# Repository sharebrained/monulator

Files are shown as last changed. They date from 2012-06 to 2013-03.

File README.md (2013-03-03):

monulator
=========

Data visualization gadget featuring an analog panel meter and RGB LED controlled over USB

Sub-Projects
============

* monulator-arm-lpc11u: NXP LPC11U14-based Monulator, the second (but probably not *last*) implementation.
* monulator-usb-avr8: Atmel AVR8-based Monulator, the first implementation.

License
=======

Please see the license files within individual project directories.

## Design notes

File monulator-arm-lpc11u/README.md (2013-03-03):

monulator-usb-avr8
==================

Data visualization gadget featuring an analog panel meter and RGB LED
controlled via USB or Wi-Fi. More information in
[this blog post](http://www.sharebrained.com/2012/05/30/the-monulator/).

Status
======

This version of the Monulator project is tested with an NXP LPC11U14
development board, TI CC3000 evaluation module, and a lot of jumper wires.
A custom circuit board design and prototype is pending.
    
License
=======

The associated software is provided under a GPLv2 license:

Copyright (C) 2013 Jared Boone, ShareBrained Technology, Inc.

This program is free software; you can redistribute it and/or
modify it under the terms of the GNU General Public License
as published by the Free Software Foundation; either version 2
of the License, or (at your option) any later version.

This program is distributed in the hope that it will be useful,
but WITHOUT ANY WARRANTY; without even the implied warranty of
MERCHANTABILITY or FITNESS FOR A PARTICULAR PURPOSE.  See the
GNU General Public License for more details.

You should have received a copy of the GNU General Public License
along with this program; if not, write to the Free Software
Foundation, Inc., 51 Franklin Street, Fifth Floor, Boston, MA
02110-1301, USA.

Contact
=======

ShareBrained Technology, Inc.

<http://www.sharebrained.com/>

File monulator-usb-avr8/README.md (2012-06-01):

monulator-usb-avr8
==================

Data visualization gadget featuring an analog panel meter and RGB LED
controlled over USB. More information in [this blog post](http://www.sharebrained.com/2012/05/30/the-monulator/).

Status
======

This board has been fabricated and assembled, and works well. The
project is still under heavy development, so expect radical changes
in the design.

Bill of Materials
=================

See the included monulator-usb-avr8-bom.csv. I believe it's up-to-date with the
components and values I used in my last build of this board. But do re-check
against the respective datasheets.

Requirements
============

* [EAGLE 5.11 Freeware, Light, Hobbyist, Standard, or Professional]
  (http://www.cadsoftusa.com/shop/pricing/)

Files
=====

* monulator-usb-avr8.sch:

    Schematic for circuit board, drawn in EAGLE 5.11.

* monulator-usb-avr8-schematic.pdf:

    Schematic for circuit board, in Adobe PDF format.

* monulator-usb-avr8-bom.csv:

    List of components used in the circuit board, including recommended vendors
    and prices.

* monulator-usb-avr8.brd:

    Circuit board layout, drawn in EAGLE 5.11.

* monulator-usb-avr8.dru:

    EAGLE design rules used to validate schematic and PCB.

* monulator-usb-avr8-laen2.cam:

    EAGLE CAM file used to generate Gerber RS-274X files for
    circuit board production via
    [Laen's two-layer PCB Order]
    (http://dorkbotpdx.org/wiki/pcb_order).
    
License
=======

This hardware design is licensed under a
[Creative Commons Attribution-ShareAlike 3.0 Unported License]
(http://creativecommons.org/licenses/by-sa/3.0/).

The associated software is provided under a BSD two-clause license:

Copyright (c) 2011, ShareBrained Technology, Inc.
All rights reserved.

Redistribution and use in source and binary forms, with or without
modification, are permitted provided that the following conditions are met:

o Redistributions of source code must retain the above copyright notice, this
  list of conditions and the following disclaimer.

o Redistributions in binary form must reproduce the above copyright notice,
  this list of conditions and the following disclaimer in the documentation
  and/or other materials provided with the distribution.

THIS SOFTWARE IS PROVIDED BY THE COPYRIGHT HOLDERS AND CONTRIBUTORS "AS IS"
AND ANY EXPRESS OR IMPLIED WARRANTIES, INCLUDING, BUT NOT LIMITED TO, THE
IMPLIED WARRANTIES OF MERCHANTABILITY AND FITNESS FOR A PARTICULAR PURPOSE
ARE DISCLAIMED. IN NO EVENT SHALL THE COPYRIGHT HOLDER OR CONTRIBUTORS BE
LIABLE FOR ANY DIRECT, INDIRECT, INCIDENTAL, SPECIAL, EXEMPLARY, OR
CONSEQUENTIAL DAMAGES (INCLUDING, BUT NOT LIMITED TO, PROCUREMENT OF
SUBSTITUTE GOODS OR SERVICES; LOSS OF USE, DATA, OR PROFITS; OR BUSINESS
INTERRUPTION) HOWEVER CAUSED AND ON ANY THEORY OF LIABILITY, WHETHER IN
CONTRACT, STRICT LIABILITY, OR TORT (INCLUDING NEGLIGENCE OR OTHERWISE)
ARISING IN ANY WAY OUT OF THE USE OF THIS SOFTWARE, EVEN IF ADVISED OF THE
POSSIBILITY OF SUCH DAMAGE.

Contact
=======

ShareBrained Technology, Inc.

<http://www.sharebrained.com/>

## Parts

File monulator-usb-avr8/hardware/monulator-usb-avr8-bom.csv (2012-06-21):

Ref Des | Mfr | Mfr Part | Description | Vendor | Vendor Part | Qty
C1,2 | TDK | C1608C0G1H180J | CAP CER 18PF 50V 5% NP0 0603 | Digi-Key | 445-1272-1-ND | 2
C3,4,9 | Murata | GRM188F51C105ZA01D | CAP CER 1UF 16V Y5V 0603 | Digi-Key | 490-1582-1-ND | 3
C5,6 | Murata | GRM188F51C104ZA01D | CAP CER .1UF 16V Y5V 0603 | Digi-Key | 490-1577-1-ND | 2
C7,8 |  |  | do not populate |  |  | 0
C10 |  |  | do not populate |  |  | 0
C11 | Murata | GRM188R60J475ME19D | CAP CER 4.7UF 6.3V 20% X5R 0603 | Digi-Key | 490-5421-1-ND | 1
D1 | Cree | CLP6C-FKB-CM1Q1H1BB7R3R3 | LED RED/GREEN/BLUE PLCC6 SMD | Digi-Key | CLP6C-FKB-CM1Q1H1BB7R3R3CT-ND | 1
F1 | Bourns | MF-NSMF050-2 | PTC RESETTABLE .50A 13.2V 1206 | Digi-Key | MF-NSMF050-2TR-ND | 1
FB1 | TDK | MPZ1608S601A | FERRITE CHIP BEAD 600 OHM SMD | Digi-Key | 445-2205-1-ND | 1
J1 | On Shore Technology | USB-B1KSB6 | CONN USB TYPE B VERTICAL BLACK | Digi-Key | ED2981-ND | 1
J2 |  | 85C1-A | 5mA panel meter |  |  | 1
J3A,J3B | Sullins | NPPN101BFCN-RC | CONN RECEPT 2MM SINGLE STR 10POS | Digi-Key | S5751-10-ND | 2
J4,5 |  |  | 2-pin 0.1” header |  |  | 2
J6 |  |  | 2x3-pin 0.1” header |  |  | 1
Q2,3,4 | NXP | 2N7002F,215 | MOSFET N-CH 60V 475MA SOT23 | Digi-Key | 568-5983-1-ND | 3
R1,2 | Yageo | RC0603JR-0722RL | RES 22 OHM 1/10W 5% 0603 SMD | Digi-Key | 311-22GRCT-ND | 2
R3 | Yageo | RC0603FR-07137RL | RES 137 OHM 1/10W 1% 0603 SMD | Digi-Key | 311-137HRCT-ND | 1
R4,5 | Yageo | RC0603FR-0776R8L | RES 76.8 OHM 1/10W 1% 0603 SMD | Digi-Key | 311-76.8HRCT-ND | 2
R6 | Yageo | RC0603FR-07590RL | RES 590 OHM 1/10W 1% 0603 SMD | Digi-Key | 311-590HRCT-ND | 1
R7 | Yageo | RC0603FR-07100RL | RES 100 OHM 1/10W 1% 0603 SMD | Digi-Key | 311-100HRCT-ND | 1
R8,9 | Yageo | RC0603FR-0710KL | RES 10.0K OHM 1/10W 1% 0603 SMD | Digi-Key | 311-10.0KHRCT-ND | 2
SW1 | TE Connectivity | FSM4JSMA | SWITCH TACTILE SPST-NO 0.05A 12V | Digi-Key | 450-1129-ND | 1
U1 | Atmel | AT90USB162-16AU | MCU AVR USB 16K FLASH 32-TQFP | Digi-Key | AT90USB162-16AU-ND | 1
U2 | Torex | XC6222B331MR-G | IC REG LDO 3.3V SOT-25 | Digi-Key | 893-1143-1-ND | 1
X1 | TXC | 7V-16.000MAAE-T | CRYSTAL 16.000 MHZ 12PF SMD | Digi-Key | 887-1462-1-ND | 1

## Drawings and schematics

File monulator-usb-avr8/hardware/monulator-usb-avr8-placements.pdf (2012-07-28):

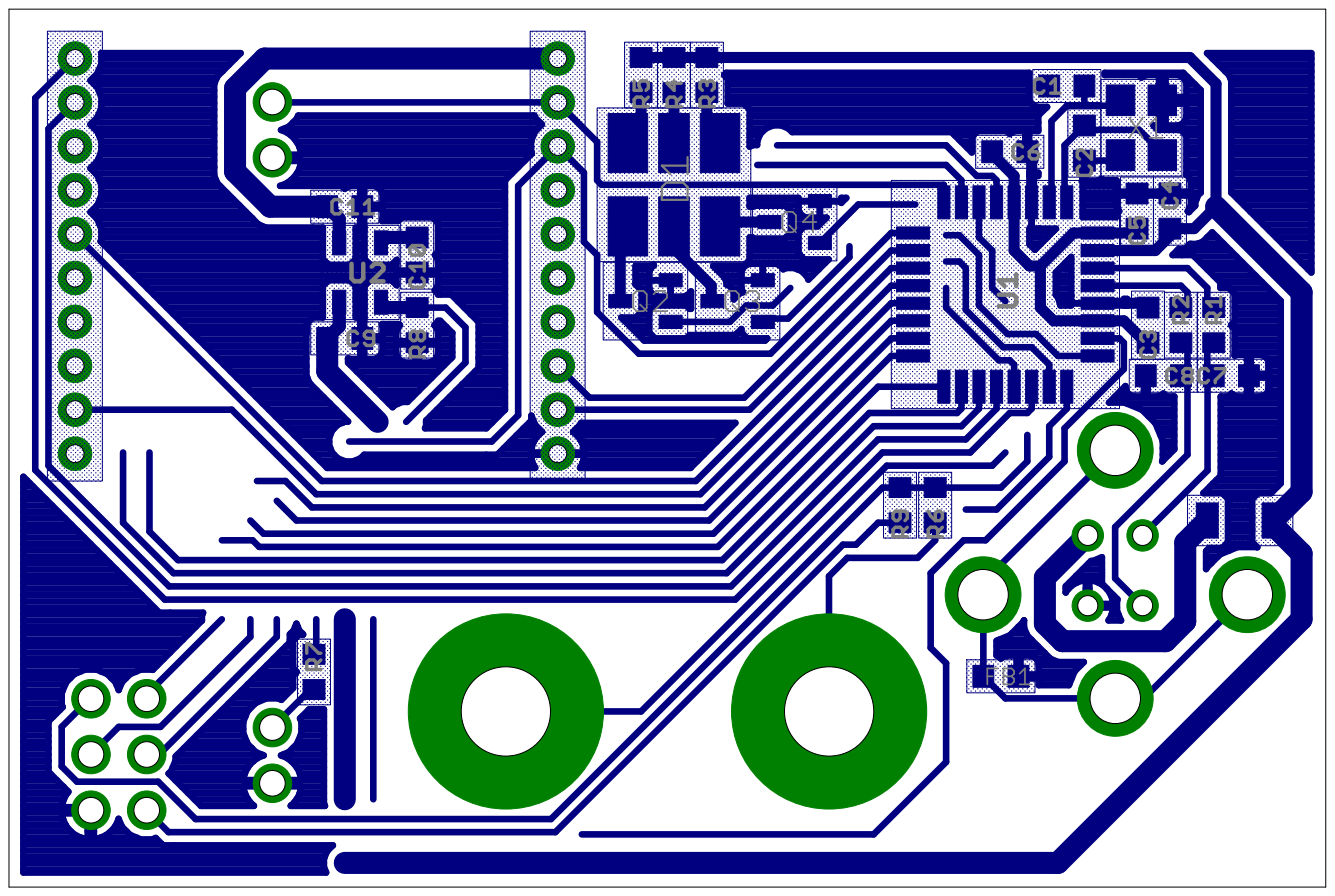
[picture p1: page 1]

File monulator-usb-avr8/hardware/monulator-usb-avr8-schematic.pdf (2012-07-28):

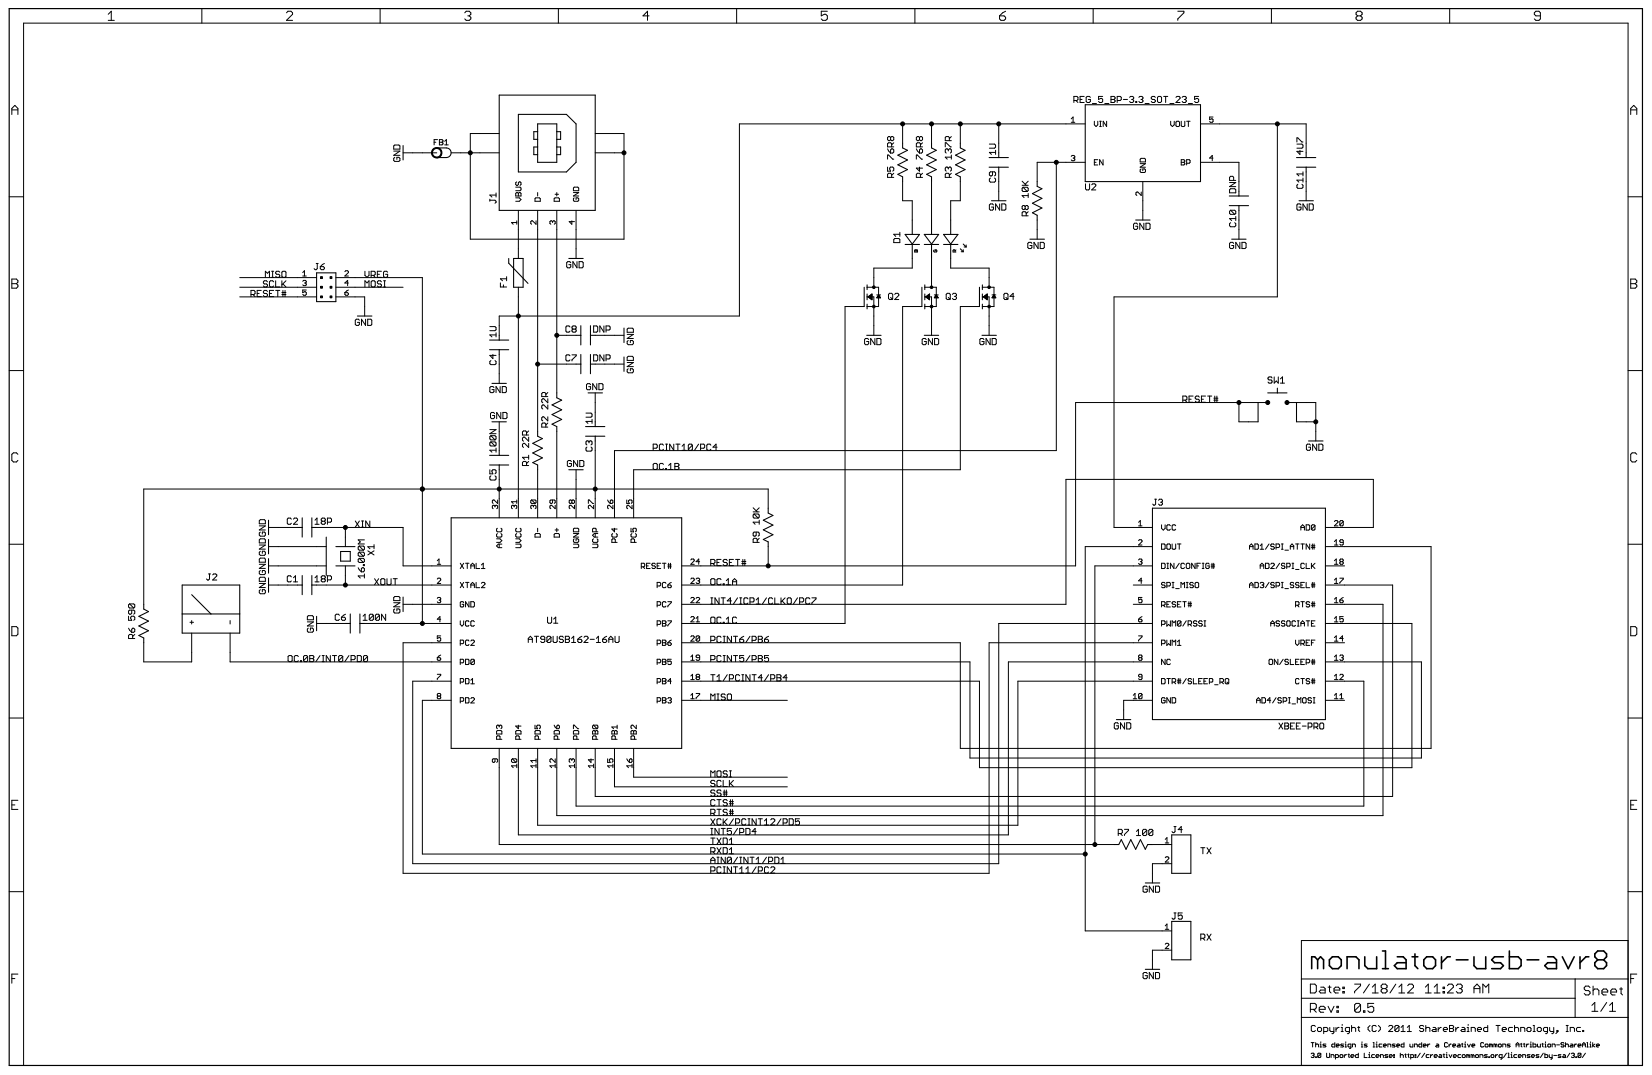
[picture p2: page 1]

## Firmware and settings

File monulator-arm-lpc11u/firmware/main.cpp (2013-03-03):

/* 
 * Monulator ARM LPC11U14 application.
 * 
 * Copyright (C) 2013 Jared Boone, ShareBrained Technology, Inc.
 * 
 * This file is part of the Monulator project.
 * 
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
 * You should have received a copy of the GNU General Public License
 * along with this program; if not, write to the Free Software
 * Foundation, Inc., 51 Franklin Street, Fifth Floor, Boston, MA
 * 02110-1301, USA.
 */

#include "lpc11u.h"
#include "serial.h"

#include "cc3000.h"
#include "cc3000_spi.h"
#include "cc3000_nvram.h"
#include "cc3000_wlan.h"
#include "cc3000_socket.h"

#include "http.h"
#include "csv_parser.h"
#include "aurora_swpc.h"

//#include "patch.h"

#include "TEST_WLAN_INFO.h"

#include <cstdint>

void turn_on_crystal_oscillator() {
	SCB.SYSOSCCTRL = 0;
	SCB.enable_power(SCB.PDRUNCFG_SYSOSC);
}

void start_system_pll() {
	// Start up system PLL: 12MHz crystal to 48 MHz.
	SCB.set_system_pll_dividers(1, 3);
	SCB.set_system_pll_clock_source(SCB.SYSPLLCLKSEL_SEL_CRYSTAL_OSCILLATOR);
	SCB.enable_power(SCB.PDRUNCFG_SYSPLL);
	SCB.wait_for_system_pll_lock();
}

void set_main_clock_to_system_pll() {
	// Switch main (and system clocks) to system PLL
	SCB.set_main_clock_source(SCB.MAINCLKSEL_SEL_PLL_OUTPUT);
}

void start_usb_pll() {
	// Start up USB PLL: 12MHz crystal to 48 MHz.
	SCB.set_usb_pll_dividers(1, 3);
	SCB.set_usb_pll_clock_source(SCB.USBPLLCLKSEL_SEL_SYSTEM_OSCILLATOR);
	SCB.enable_power(SCB.PDRUNCFG_USBPLL);
	SCB.wait_for_usb_pll_lock();
}

void set_usb_clock_to_main_clock() {
	// NOTE: Both clock sources must be running in order to switch!
	// So if you want to use the main clock instead of the USB PLL,
	// you have to start the USB PLL in order to switch away from it!
	SCB.set_usb_clock_source(SCB.USBCLKSEL_SEL_MAIN_CLOCK);
}

void set_usb_clock_to_usb_pll() {
	SCB.set_usb_clock_source(SCB.USBCLKSEL_SEL_USB_PLL_OUT);
}

void enable_peripheral_clocks() {
	SCB.set_system_clock_divider(1);
	SCB.enable_clocks(
		  SCB.SYSAHBCLKCTRL_GPIO
		//| SCB.SYSAHBCLKCTRL_CT16B0
		//| SCB.SYSAHBCLKCTRL_CT16B1
		//| SCB.SYSAHBCLKCTRL_CT32B0
		| SCB.SYSAHBCLKCTRL_CT32B1
		| SCB.SYSAHBCLKCTRL_USART
		| SCB.SYSAHBCLKCTRL_SSP1
		| SCB.SYSAHBCLKCTRL_USB
		| SCB.SYSAHBCLKCTRL_IOCON
		//| SCB.SYSAHBCLKCTRL_RAM1	// Available on larger parts.
		| SCB.SYSAHBCLKCTRL_USBRAM
	);
}

void enable_clock_output() {
	SCB.set_clkout_clock_source(SCB.CLKOUTSEL_SEL_MAIN_CLOCK);
	SCB.set_clkout_divider(48);
	IOCON.PIO0_1 = 1;
}

void configure_pins() {
	// Enable LED output
	GPIO_PORT.DIR0 |=
		(1 << 7)
		;
	
	// CT16B0_MAT PWM outputs
	/*
	IOCON.PIO0_8 = 2;
	IOCON.PIO0_9 = 2;
	IOCON.PIO1_15 = 2;
	*/
	
	// CT32B1_MAT PWM outputs
	/*
	IOCON.TDO_PIO0_13 = 3;	// CT32B1_MAT0
	IOCON.TRST_PIO0_14 = 3;	// CT32B1_MAT1
	IOCON.PIO0_16 = 2;		// CT32B1_MAT3
	*/
	
	// Configure USART
	IOCON.PIO0_18 = 1;		// RXD
	IOCON.PIO0_19 = 1;		// TXD
	
	// Configure USB I/O
	IOCON.PIO0_3 = 1;		// USB_VBUS
	IOCON.PIO0_6 = 1;		// USB_CONNECT#
	SCB.enable_power(SCB.PDRUNCFG_USBPAD);
	
	// Configure CC3000 EN and IRQ
	cc3000.disable();
	
	// CC3000_EN:   PIO, output
	GPIO_PORT.DIR1 |= (1 << 22);
	IOCON.PIO1_22 = 0;		
	
	// CC3000_IRQ#: PIO, input
	// Pull-up ensures IRQ# is inactive when module is off.
	GPIO_PORT.DIR1 &= ~(1 << 27);
	IOCON.PIO1_27 = (2 << 3); // pull-up resistor enabled.
	
	// CC3000_CS#:  PIO, output
	GPIO_PORT.DIR1 |= (1 << 23);
	IOCON.PIO1_23 = 0;
	
	// Configure SPI I/O
	IOCON.PIO1_20 = 2;		// CC3000_SCLK: SCLK1
	IOCON.PIO0_21 = 2;		// CC3000_MOSI: MOSI1
	IOCON.PIO1_21 = 2;		// CC3000_MISO: MISO1
}

void configure_led_pwm_timer_ct16b0() {
	// Configure 16 bit timer/match 0
	CT16B0.TCR = (1 << 1);
	CT16B0.TCR = 0;

	CT16B0.PC = 0;
	CT16B0.TC = 0;

	CT16B0.PR = 0;
	
	CT16B0.MR[0] = 12000;	// Channel 1 low time
	CT16B0.MR[1] = 24000;	// Channel 2 low time
	CT16B0.MR[2] = 36000;	// Channel 3 low time
	CT16B0.MR[3] = 48000;	// Cycle count.
	CT16B0.MCR = (1 << 10);
	CT16B0.EMR = 0;
	CT16B0.PWMC =
		  (1 << 2)
		| (1 << 1)
		| (1 << 0)
		;
		
	CT16B0.TCR = (1 << 0);
}

void configure_led_pwm_timer_ct32b1() {
	// Configure 32 bit timer/match 1
	CT32B1.TCR = (1 << 1);
	CT32B1.TCR = 0;

	CT32B1.PC = 0;
	CT32B1.TC = 0;

	CT32B1.PR = 0;
	
	CT32B1.MR[0] = 12000;	// Channel 1 low time
	CT32B1.MR[1] = 24000;	// Channel 2 low time
	CT32B1.MR[2] = 48000;	// Cycle count.
	CT32B1.MR[3] = 36000;	// Channel 4 low time
	CT32B1.MCR = (1 << 7);
	CT32B1.EMR = 0;
	CT32B1.PWMC =
		  (1 << 3)
		| (1 << 1)
		| (1 << 0)
		;
		
	CT32B1.TCR = (1 << 0);
}

void configure_usb() {
	// TODO: Start up USB PLL separately, just to free up main clock to be adjustable?
	set_usb_clock_to_usb_pll();
	SCB.set_usb_clock_divider(1);

	usb_endpoint_list_t* endpoint_list = reinterpret_cast<usb_endpoint_list_t*>(0x20004000);
	endpoint_list->ep[0].out[0] = (64 << 16) | (0x200040C0 >> 6);
	endpoint_list->ep[0].out[1] = (0x20004080 >> 6);
	endpoint_list->ep[0].in[0] = (64 << 16) | (0x20004100 >> 6);
	endpoint_list->ep[0].in[1] = 0;
	
	USB.set_endpoint_list_start_address(endpoint_list);
	USB.set_data_buffer_start_address(0x20004000);
	USB.enable_device();
	USB.clear_all_interrupts();
	USB.enable_all_interrupts();
	USB.enable_connect();
}

void init_cc3000(const simplelink_patches_request_t patches_request=SIMPLELINK_PATCHES_REQUEST_DEFAULT) {
	delay(5000000);

	serial_write_line("disabling...");
	cc3000.disable();

	delay(5000000);
	
	serial_write_string("enabling with patches: ");
	switch(patches_request) {
	case SIMPLELINK_PATCHES_REQUEST_DEFAULT:
		serial_write_line("default");
		break;

	case SIMPLELINK_PATCHES_REQUEST_FORCE_HOST:
		serial_write_line("force host");
		break;

	case SIMPLELINK_PATCHES_REQUEST_FORCE_NONE:
		serial_write_line("force none");
		break;
	}
	
	cc3000.enable(patches_request);
	
	cc3000_wlan.smartconfig_set_prefix();
	cc3000_wlan.ioctl_set_connection_policy(false, false, false);
	cc3000_wlan.ioctl_del_profile(255);
	cc3000_wlan.set_event_mask((hci_event_mask_t)(
		  HCI_EVENT_MASK_WLAN_KEEPALIVE
		| HCI_EVENT_MASK_WLAN_INIT
		| HCI_EVENT_MASK_WLAN_ASYNC_PING_REPORT
		)
	);
}

void display_buffers_info() {
	const auto buffer_size = cc3000.read_buffer_size();
	serial_write_string("buffers: 0x");
	serial_write_hex(buffer_size.number_of_free_buffers);
	serial_write_string(" x 0x");
	serial_write_hex(buffer_size.buffer_length);
	serial_write_line();
}

void display_sp_version() {
	const auto sp_version = cc3000_nvram.read_sp_version();
	serial_write_string("sp_version: 0x");
	serial_write_hex(sp_version.package_id);
	serial_write_string(".0x");
	serial_write_hex(sp_version.package_build_number);
	serial_write_line();
}

void dump_nvram_file(const nvram_file_id_t file_id, const size_t file_length) {
	std::array<uint8_t, 150> buffer;
	const size_t offset_end = file_length;
	for(size_t offset=0; offset<file_length; offset+=buffer.size()) {
		const size_t remaining = offset_end - offset;
		const size_t length = (remaining < buffer.size()) ? remaining : buffer.size();
		if( cc3000_nvram.read(file_id, length, offset, buffer.data()) == HCI_EVENT_STATUS_OK ) {
			//serial_write_hex(offset, 4);
			//serial_write(':');
			for(size_t i=0; i<length; i++) {
				serial_write(' ');
				serial_write_hex(buffer[i], 2);
			}
			serial_write(',');
		}
	}
}
/*
class http_response_sink_log_t : public sink_t {
	virtual int do_sink(const void* const data, const size_t length) override {
		serial_write_buffer((const uint8_t*)data, length);
		return 0;
	}
};

class csv_sink_log_t : public csv_sink_t {
	virtual int do_csv_cell(const size_t column, const size_t row, const void* const data, const size_t data_length) override {
		serial_write_hex(column, 1);
		serial_write(',');
		serial_write_hex(row, 1);
		serial_write('=');
		serial_write_buffer((const uint8_t*)data, data_length);
		serial_write_line();
		return 0;
	}
};
*/
extern "C" int main() {
	turn_on_crystal_oscillator();
	start_system_pll();
	start_usb_pll();
	set_main_clock_to_system_pll();
	enable_peripheral_clocks();
	serial_init();

	configure_pins();
	
	configure_led_pwm_timer_ct32b1();

	//enable_clock_output();
	/*
	configure_usb();
	
	while(1) {
		GPIO_WORD.W[7] = USB.setup_token_received();
		//GPIO_PORT.NOT0 = (1 << 7);
		//do_work();
	}
	*/
	
	SCB.set_ssp1_clock_divider(1);
	SCB.reset_ssp1_peripheral();

	// Bit frequency = pclk / (cpsdvsr * (scr + 1))
	// pclk = 48MHz
	const uint32_t scr = 0;
	const uint32_t cpsdvsr = 48;
		
	SSP1.CR0 =
		  (scr << 8)
		| (1 << 7)		// CPHA=1 (capture data on clock return to idle)
		| (0 << 6)		// CPOL=0 (clock low between frames)
		| (0 << 4)		// SPI
		| (7 << 0)		// 8-bit transfer
		;
		
	SSP1.CR1 =
		  (0 << 2)		// SPI mode: master
		| (0 << 1)		// SPI controller: disabled
		| (0 << 0)		// Loopback mode: off (normal)
		;
		
	SSP1.CPSR =
		  (cpsdvsr << 0)
		;
	
	SSP1.IMSC =
		  (0 << 3)		// TXIM
		| (0 << 2)		// RXIM
		| (0 << 1)		// RTIM
		| (0 << 0)		// RORIM
		;
	
	SSP1.ICR =
		  (1 << 1)		// RTIC
		| (1 << 0)		// RORIC
		;

	// Enable SPI
	SSP1.CR1 |= (1 << 1);
	
	NVIC.enable_interrupts();
	
	init_cc3000();

	cc3000_wlan.connect(WLAN_SSID, {{0,0,0,0,0,0}}, WLAN_KEY);
	while( !cc3000_wlan.is_dhcp() ) {
		cc3000.check_for_unsolicited_events();
	}
	
	GPIO_PORT.SET0 = (1 << 7);
	
	aurora_swpc_t aurora_swpc;
	csv_parser_t csv_parser(' ', aurora_swpc);
	//csv_sink_log_t csv_log_sink;
	//csv_parser_t csv_parser(' ', csv_log_sink);
	http_connection_t connection(csv_parser);
	
	//http_response_sink_log_t http_response_sink;
	//http_connection_t connection(http_response_sink);
	
	connection.open("www.swpc.noaa.gov", 80, "/ftpdir/lists/hpi/activity.dat");
	connection.close();
	
	serial_write_string("aurora: ");
	serial_write_hex(aurora_swpc.level(), 1);
	serial_write_line();
	
	while(true) {
		cc3000.check_for_unsolicited_events();
		
		if( cc3000_wlan.is_connected() ) {
			GPIO_PORT.SET0 = (1 << 7);
		} else {
			GPIO_PORT.CLR0 = (1 << 7);
		}
	}
	
	return 0;
}

extern "C" void SystemInit() {
	
}
/*
#include <errno.h>
extern "C" int _kill(int pid, int sig) {
	errno = ENOSYS;
	return -1;
}
*/

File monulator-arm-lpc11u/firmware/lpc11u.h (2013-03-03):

/* 
 * NXP LPC11U14 peripheral definitions and wrapper classes.
 * 
 * Copyright (C) 2013 Jared Boone, ShareBrained Technology, Inc.
 * 
 * This file is part of the Monulator project.
 * 
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
 * You should have received a copy of the GNU General Public License
 * along with this program; if not, write to the Free Software
 * Foundation, Inc., 51 Franklin Street, Fifth Floor, Boston, MA
 * 02110-1301, USA.
 */

#ifndef LPC11U_H_6MHWJJ4R
#define LPC11U_H_6MHWJJ4R

#include <cstdint>
#include <cstddef>

using reg_t = uint32_t;
using reg_readwrite_t = volatile reg_t;
using reg_readonly_t = volatile const reg_t;

struct reg_writeonly_t {
	reg_writeonly_t() = delete;
	reg_writeonly_t(reg_writeonly_t&) = delete;
	
	reg_writeonly_t& operator=(const reg_t value) {
		reg = value;
		return *this;
	}
	
private:
	reg_t reg;
	
	static void _assert_struct() {
		static_assert(sizeof(reg_writeonly_t) == 4, "reg_writeonly_t size not correct");
	}
};

struct reg_reserved_t {
	reg_reserved_t() = delete;
	reg_reserved_t(reg_reserved_t&) = delete;
	
private:
	reg_t reg;
	
	static void _assert_struct() {
		static_assert(sizeof(reg_reserved_t) == 4, "reg_writeonly_t size not correct");
	}
};

struct NVIC_t {
	NVIC_t() = delete;
	NVIC_t(NVIC_t&) = delete;
	
	enum IRQN_TYPE_t {
		IRQN_TYPE_PIN_INT0 = 0,
		IRQN_TYPE_PIN_INT1 = 1,
		IRQN_TYPE_PIN_INT2 = 2,
		IRQN_TYPE_PIN_INT3 = 3,
		IRQN_TYPE_PIN_INT4 = 4,
		IRQN_TYPE_PIN_INT5 = 5,
		IRQN_TYPE_PIN_INT6 = 6,
		IRQN_TYPE_PIN_INT7 = 7,
		IRQN_TYPE_GINT0 = 8,
		IRQN_TYPE_GINT1 = 9,
		IRQN_TYPE_SSP1 = 14,
		IRQN_TYPE_I2C = 15,
		IRQN_TYPE_CT16B0 = 16,
		IRQN_TYPE_CT16B1 = 17,
		IRQN_TYPE_CT32B0 = 18,
		IRQN_TYPE_CT32B1 = 19,
		IRQN_TYPE_SSP0 = 20,
		IRQN_TYPE_USART = 21,
		IRQN_TYPE_USB_IRQ = 22,
		IRQN_TYPE_USB_FIQ = 23,
		IRQN_TYPE_ADC = 24,
		IRQN_TYPE_WWDT = 25,
		IRQN_TYPE_BOD = 26,
		IRQN_TYPE_FLASH = 27,
		IRQN_TYPE_USB_WAKEUP = 30,
	};
	
	static void enable_interrupts() {
		__asm__("cpsie i");
	}
	
	static void disable_interrupts() {
		__asm__("cpsid i");
	}
	
	void enable_irq(const IRQN_TYPE_t irqn) {
		ISER = (1 << irqn);
	}
	
	void disable_irq(const IRQN_TYPE_t irqn) {
		ICER = (1 << irqn);
	}
	
	reg_readwrite_t		ISER;
	reg_reserved_t		_reserved_0x004[31];
	reg_readwrite_t		ICER;
	reg_reserved_t		_reserved_0x084[31];
	reg_readwrite_t		ISPR;
	reg_reserved_t		_reserved_0x104[31];
	reg_readwrite_t		ICPR;
	reg_reserved_t		_reserved_0x184[31];
	reg_reserved_t		_reserved_0x200[64];
	reg_readwrite_t		IPR[8];
	
private:
	static void _assert_struct() {
		static_assert(sizeof(NVIC_t) == 0x320, "NVIC_t size is wrong");
	}
};

struct SCB_t {
	SCB_t() = delete;
	SCB_t(SCB_t&) = delete;
	
	void reset_ssp1_peripheral() {
		PRESETCTRL &= ~(1 << 2);
		PRESETCTRL |= (1 << 2);
	}
	
	bool is_system_pll_locked() {
		return (SYSPLLSTAT & 1) != 0;
	}
	
	void wait_for_system_pll_lock() {
		while( !is_system_pll_locked() );
	}
	
	enum SYSPLLCLKSEL_SEL_t {
		SYSPLLCLKSEL_SEL_IRC_OSCILLATOR = 0x0,
		SYSPLLCLKSEL_SEL_CRYSTAL_OSCILLATOR = 0x1,
	};
	
	void set_system_pll_clock_source(const SCB_t::SYSPLLCLKSEL_SEL_t value) {
		SYSPLLCLKSEL = value;
		SYSPLLCLKUEN = 0;
		SYSPLLCLKUEN = 1;
	}
	
	void set_system_pll_dividers(const reg_t psel, const reg_t msel) {
		SYSPLLCTRL =
	 		  (psel << 5)
			| (msel << 0)
			;
	}
	
	void set_system_clock_divider(const reg_t value) {
		SYSAHBCLKDIV = value;
	}
	
	void disable_system_clock_divider() {
		set_system_clock_divider(0);
	}
	
	enum MAINCLKSEL_SEL_t {
		MAINCLKSEL_SEL_IRC_OSCILLATOR = 0x0,
		MAINCLKSEL_SEL_PLL_INPUT = 0x1,
		MAINCLKSEL_SEL_WATCHDOG_OSCILLATOR = 0x2,
		MAINCLKSEL_SEL_PLL_OUTPUT = 0x3,
	};

	void set_main_clock_source(const SCB_t::MAINCLKSEL_SEL_t value) {
		MAINCLKSEL = value;
		MAINCLKUEN = 0;
		MAINCLKUEN = 1;
	}
	
	enum SYSAHBCLKCTRL_t {
		SYSAHBCLKCTRL_SYS			= (1 <<  0),
		SYSAHBCLKCTRL_ROM			= (1 <<  1),
		SYSAHBCLKCTRL_RAM0			= (1 <<  2),
		SYSAHBCLKCTRL_FLASHREG		= (1 <<  3),
		SYSAHBCLKCTRL_FLASHARRAY	= (1 <<  4),
		SYSAHBCLKCTRL_I2C			= (1 <<  5),
		SYSAHBCLKCTRL_GPIO			= (1 <<  6),
		SYSAHBCLKCTRL_CT16B0		= (1 <<  7),
		SYSAHBCLKCTRL_CT16B1		= (1 <<  8),
		SYSAHBCLKCTRL_CT32B0		= (1 <<  9),
		SYSAHBCLKCTRL_CT32B1		= (1 << 10),
		SYSAHBCLKCTRL_SSP0			= (1 << 11),
		SYSAHBCLKCTRL_USART			= (1 << 12),
		SYSAHBCLKCTRL_ADC			= (1 << 13),
		SYSAHBCLKCTRL_USB			= (1 << 14),
		SYSAHBCLKCTRL_WWDT			= (1 << 15),
		SYSAHBCLKCTRL_IOCON			= (1 << 16),
		SYSAHBCLKCTRL_SSP1			= (1 << 18),
		SYSAHBCLKCTRL_PINT			= (1 << 19),
		SYSAHBCLKCTRL_GROUP0INT		= (1 << 23),
		SYSAHBCLKCTRL_GROUP1INT		= (1 << 24),
		SYSAHBCLKCTRL_RAM1			= (1 << 26),
		SYSAHBCLKCTRL_USBRAM		= (1 << 27),
	};

	void enable_clocks(const reg_t value) {
		SYSAHBCLKCTRL |= value;
	}
	
	bool is_usb_pll_locked() {
		return (USBPLLSTAT & 1) != 0;
	}
	
	void wait_for_usb_pll_lock() {
		while( !is_usb_pll_locked() );
	}
	
	void set_usb_pll_dividers(const reg_t psel, const reg_t msel) {
		USBPLLCTRL =
	 		  (psel << 5)
			| (msel << 0)
			;
	}
	
	enum USBPLLCLKSEL_SEL_t {
		USBPLLCLKSEL_SEL_IRC_OSCILLATOR = 0x0,
		USBPLLCLKSEL_SEL_SYSTEM_OSCILLATOR = 0x1,
	};
	
	void set_usb_pll_clock_source(const SCB_t::USBPLLCLKSEL_SEL_t value) {
		USBPLLCLKSEL = value;
		USBPLLCLKUEN = 0;
		USBPLLCLKUEN = 1;
	}
	
	void set_ssp0_clock_divider(const reg_t divisor) {
		SSP0CLKDIV = divisor;
	}
	
	void disable_ssp0_clock() {
		set_ssp0_clock_divider(0);
	}
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

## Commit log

2011-12-01 Release 0.1 (20111106) of the Monulator USB to Laen's PCB order.
    [monulator-usb-avr8.brd, monulator-usb-avr8.sch]
2011-12-01 Changes (?) for producing stencils. Among the things I remember: backing out the "cream" layer to 2mil/100%/2mil.
    [monulator-usb-avr8.brd, monulator-usb-avr8.sch]
2011-12-14 Add PDFs of QFN schematic and component placements.
2011-12-15 AT90USB162 QFN bill of materials, as built with boards received from the Laen PCB order 2011/11/06.
    [monulator-usb-avr8-bom.csv]
2011-12-21 Simplified design: use TQFP instead of QFN, remove LED and current-limiting resistors, simplify meter circuit (removing multiple current ranges and ability to flip meter polarity), removed RESET# pul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
    [monulator-usb-avr8-bom.csv, monulator-usb-avr8.brd, monulator-usb-avr8.sch]
2011-12-21 Removed VUSB ferrite bead, current-limiting PTC fuse. Switched 10uF VUSB to 1uF, which should be plenty for the intended use.
    [monulator-usb-avr8-bom.csv, monulator-usb-avr8.brd, monulator-usb-avr8.sch]
2012-01-02 Monulator version 0.3, design submitted to Laen PCB order 2012/01/01.
    [monulator-usb-avr8.brd, monulator-usb-avr8.sch]
2012-01-11 Update board with better pin 1 silkscreen. Update schematic and placement PDFs.
    [monulator-usb-avr8.brd, monulator-usb-avr8.sch]
2012-01-11 Updated BOM with components added to last board revision. Added LED resistor values to schematic and BOM. Added estimated assembly costs to BOM.
    [monulator-usb-avr8-bom.csv, monulator-usb-avr8.brd, monulator-usb-avr8.sch]
2012-03-03 Schematic of version 0.3, with some component values updated based on testing.
2012-06-01 Moved monulator-usb-avr8 into the modulator directory, in preparation for moving the project to a separate repository. Also imposed the hardware/firmware/software structure on the project.
    [monulator-usb-avr8-bom.csv, monulator-usb-avr8.brd, monulator-usb-avr8.sch]
2012-06-01 Revert "Moved monulator-usb-avr8 into the modulator directory, in preparation for moving the project to a separate repository. Also imposed the hardware/firmware/software structure on the project."
    This reverts commit 4dcef03214dcdaad2d0ad1651d669ac52760fdef.
    [monulator-usb-avr8-bom.csv, monulator-usb-avr8.brd, monulator-usb-avr8.sch]
2012-06-01 Reorganized monulator-usb-avr8 files into project directory with hardware/, firmware/, software/ structure.
    [monulator-usb-avr8-bom.csv, monulator-usb-avr8.brd, monulator-usb-avr8.sch]
2012-06-01 Updated schematic to include license and revision in documentation block.
    [monulator-usb-avr8.sch]
2012-06-01 Convert USB connector to vertical type B. Change crystal to HC49/US. Update revision to 0.4-dev.
    [monulator-usb-avr8.brd, monulator-usb-avr8.sch]
2012-06-02 Changed USB type B vertical connector to support four-tab shield design.
    [monulator-usb-avr8.brd, monulator-usb-avr8.sch]
2012-06-02 Recalculated AVR crystal load capacitors. Updated BOM.
    [monulator-usb-avr8-bom.csv, monulator-usb-avr8.brd, monulator-usb-avr8.sch]
2012-06-02 Reworked supply scheme so that AVR I/O is running at 3V3. This requires MOSFETs on LED drive, and allows elimination of MOSFET on meter drive.
    [monulator-usb-avr8.brd, monulator-usb-avr8.sch]
2012-06-21 Massive update of design: - Added Xbee wireless module support, associated voltage regulator. - Microcontroller running from internal regulator to provide 3V3 interface to wireless module. - MOSFETs 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
    Also cleaned up CAM file -- particularly section names, and removed cream section.
    [monulator-usb-avr8-bom.csv, monulator-usb-avr8.brd, monulator-usb-avr8.sch]
2012-07-09 Schematic and placements as built on v0.4 boards, 2012/07/08.
2012-07-28 Version 0.5 sent to OSHPark 2012/07/26. Flipped polarity of panel meter on board. Removed ISP signals attached to wireless module, as they inhibited programming. Disconnected wireless module RESET#, 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
    [monulator-usb-avr8.brd, monulator-usb-avr8.sch]
2013-01-27 Monulator ARM LPC11U board is routed. Entertaining significant changes (e.g. removing Roving Networks module altogether, offering UART interface for access to built-in bootloader).
    [monulator-arm-lpc11u.brd, monulator-arm-lpc11u.sch]
2013-01-27 Aggressive clean-up of schematic. Fixed meter polarity problem and am now driving meter open-drain. Added logos and labels.
    [monulator-arm-lpc11u.brd, monulator-arm-lpc11u.sch]
2013-03-03 Reference to ARM LPC11U subproject.
